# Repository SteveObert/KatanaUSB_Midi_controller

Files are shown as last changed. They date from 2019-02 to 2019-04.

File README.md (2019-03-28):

# A Teensy based USB MIDI foot controller/translator
# for Boss Katana.

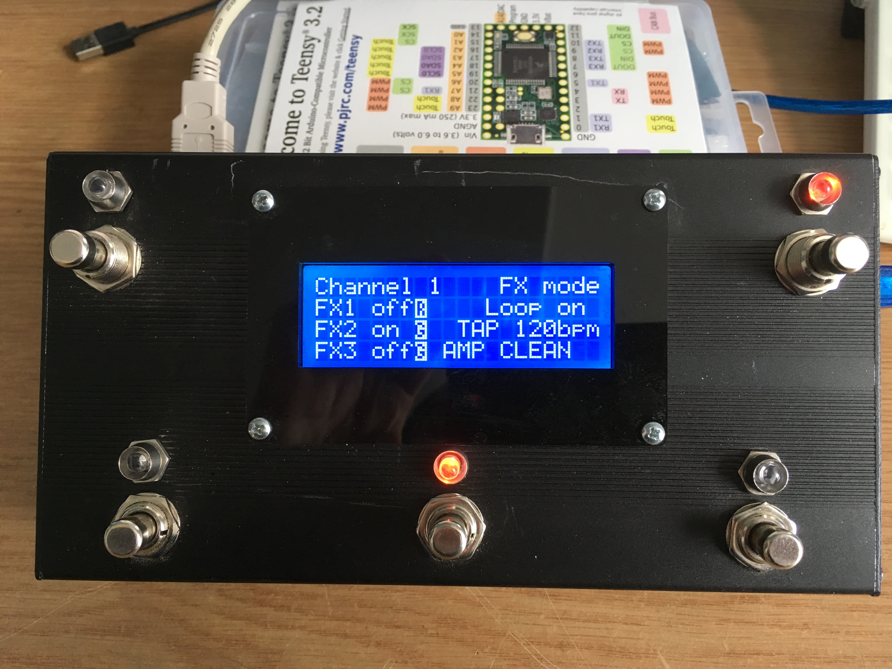
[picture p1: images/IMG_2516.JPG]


This is working prototype of a MIDI foot controller for a BOSS Katana using a Teensy 3.2. The foot controller sends sysex messages to the USB port on the Katana. The code emulates a GA-FC without additional footswitch connections (although there doesn’t seem to be any reason that’s not possible). I'm working on an expression pedal input. An expression pedal attached to an external MIDI controller can be used but requires you to adjust/write some code.

This controller can also listen to a 5 pin MIDI IN port and can be programed to translate MIDI messages (PC, CC, etc.) to sysex and forward those to a Katana. However, you must know the Katana sysex. Sending MIDI OUT from the footswitch is also possible.

It seems stable; however, it has only been tested by two people that I am aware of.

**Consider this unsupported beta software. ** If you get stuck, I may not be able to help you.

There are two versions:

In the Katana_USB_MIDI version, LCD and LEDs are updated from the Katana's USB MIDI messages. Meaning, they should take of themselves. Gumtown from the Vguitar forum deserves recognition for rewriting most of the code and adding a great deal of functionality. There is a forum thread reguarding updates and functions: https://www.vguitarforums.com/smf/index.php?topic=25185.0 

Included in the : Katana_USB_MIDI version

* Tap tempo: global or patch.

* Selectable mode for 3 foot switches, toggle either one or both FX/MOD, Delay 1/FX, and Reverb/Delay 2.

* Midi IN - control Katana patch and FX from an external MIDI controller.  *Some* CC and PC messages from the MIDI in port can be received and translated to sysex and forwarded to the Katana. If you’re looking for a more complete external MIDI to Katana you could buy the MIDX-20.

* LCD displays FX status, amp name, tempo, loop status, bank/fx mode, and channel number.

* Select Green, Yellow, or Red effect functions from the three lower foot switches.

* An expression pedal can be connected to an external MIDI controller to control 1 effect only. This is experimental and requires some coding on your part.

* Expression pedal jack input directly connected to controller and external MIDI clock IN is being worked on but not yet complete, *no ETA*.

* There is also a BOM (parts list) in this thread. This version has been tested on a Teensy 3.2 and a Teensy LC.

In the Simple sketch version, you will need to code the LCD and LEDs to work for your needs. This version is really just for testing your hardware or if you just want a starting point for your own code. The LCD and LEDs are programed to be off when you switch channels, meaning the controller expects all effects to be off. So, you'll need to change the programming if you use it differently. On this version there is no tap-tempo and no expression pedal input.

** Note I had to compile the sketches with the "fast + LTO" setting or debug, otherwise the USB mini host shield would not work. You must select the Teensy option "MIDI" when powered externally (not connected to a computer). Also, you should use the modified versions of the MS3 library included above (top of page).

Along with the Teensy 3.2, I use a Mini USB Host shield like this one: https://www.circuitsathome.com/usb-host-shield-hardware-manual/ along with the host shield library: https://github.com/felis/USB_Host_Shield_2.0.

Roland/Boss guitar gear uses a non-class compliant USB device for midi control. Additionally, there is a checksum included in each sysex message. I found this library made for the BOSS MS3:  https://github.com/MrHaroldA/MS3. Note, this library is included in the files above (top of page) and has been modified to work with the Katana instead of the MS3.
   
Here is some excellent information about sysex messages and Katana amps: https://github.com/snhirsch/katana-midi-bridge/blob/master/doc/katana_sysex.txt

The working prototype uses the library https://github.com/felis/USB_Host_Shield_2.0 and a USB host shield
(https://www.amazon.com/gp/product/B0777DR3T6/ref=ppx_yo_dt_b_asin_title_o03__o00_s00?ie=UTF8&psc=1)

I used a MIDI break out board but there no reason not to build your own MIDI in/out circuit. https://www.amazon.com/ubld-it-MIDI-Breakout-Board/dp/B00YDLVLVO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. If you don't need 5 pin MIDI IN/OUT, you can just skip this part.

What got me started on this project is a forum thread created by the author of the MS3 library: 
https://www.vguitarforums.com/smf/index.php?topic=21864.0

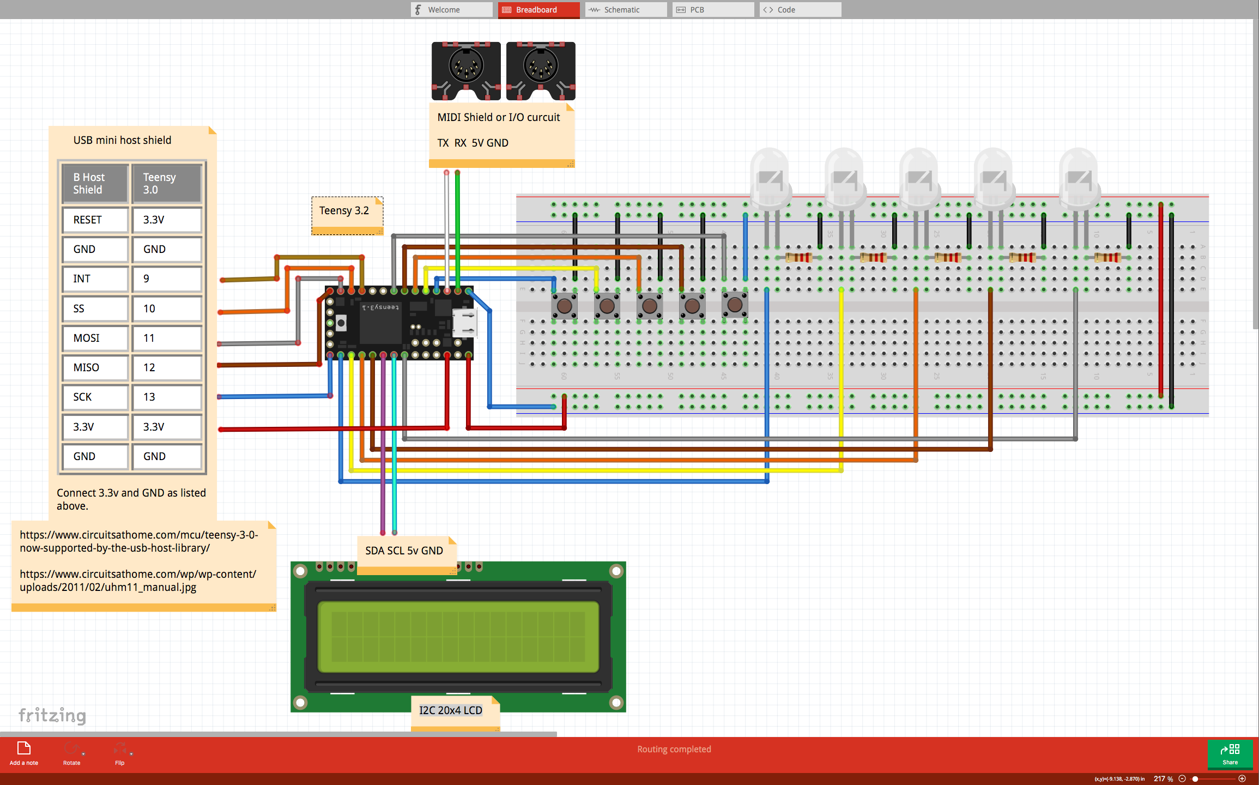
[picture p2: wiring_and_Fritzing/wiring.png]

Wiring shown above does not include expression pedals or MIDI through, see images directory for that diagram.

* I don't know if this is necessary but, I originally tested this project with an Arduino Nano and I "cut the trace inside VBUS jumper" on the host shield as mentioned in the second paragraph under the Power Options part of this page: https://www.circuitsathome.com/usb-host-shield-hardware-manual/ shown here: https://www.pjrc.com/teensy/td_libs_USBHostShield.html. I googled these pictures that show the modification for 5v microcntrollers: https://geekhack.org/index.php?PHPSESSID=jnim6u2dcno62u8vpbm8sl9ias67hb3o&action=dlattach;topic=80421.0;attach=130856;image
and https://geekhack.org/index.php?PHPSESSID=jnim6u2dcno62u8vpbm8sl9ias67hb3o&action=dlattach;topic=80421.0;attach=130858;image

These sketches have only been tested with a Teensy 3.2 and a Teensy LC. 

Inside view with messy wiring and extra holes from a previous project:

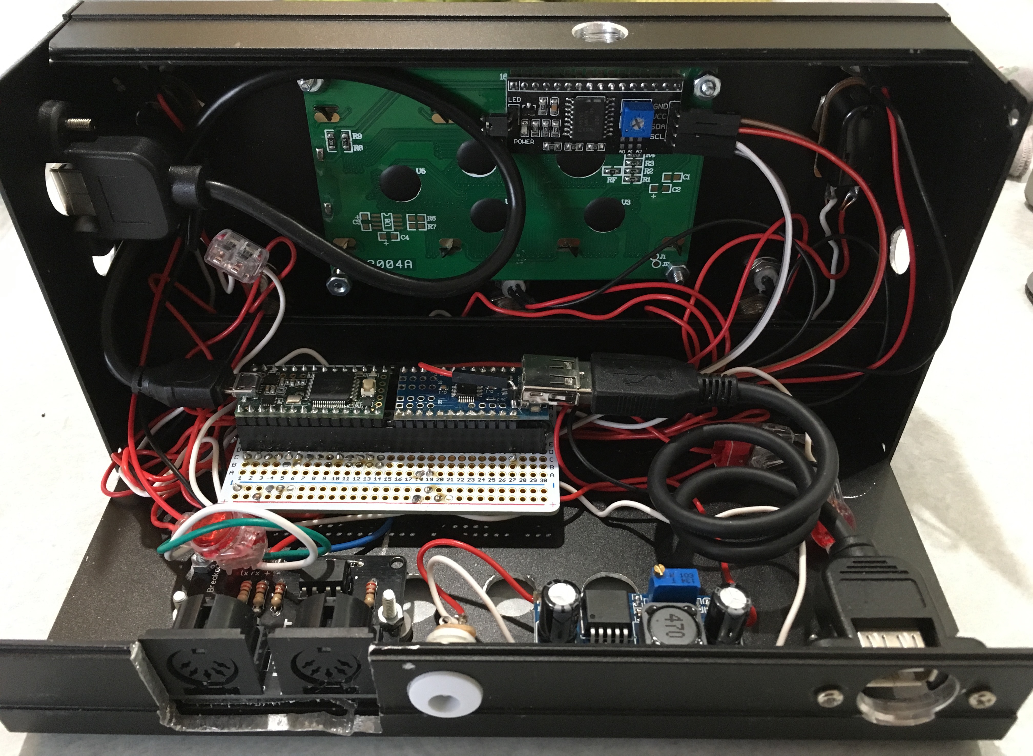
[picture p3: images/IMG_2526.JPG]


Another inside view but with a Teensy 3.6, MIDI through (untested), an extra power jack for daisy chaining, and two TRS jacks (only one is connected in the picture). A Teensy 3.2 would work just as well with ths options.

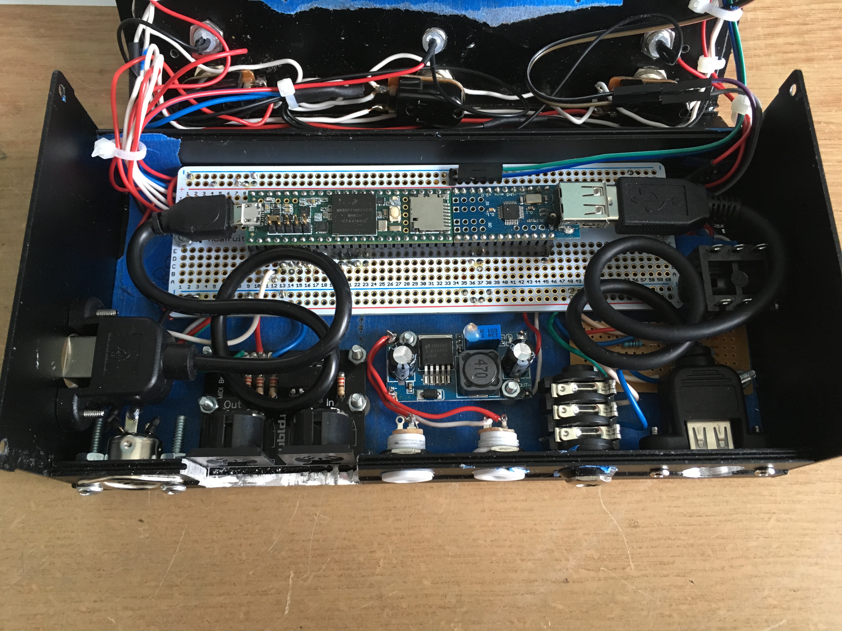
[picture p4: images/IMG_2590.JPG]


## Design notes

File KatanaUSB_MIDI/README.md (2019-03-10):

# Teensy MIDI controller for Katana 100
## Warning Beta code 

All three files must be in the same directory to complie properly.

In this version of the sketch the LCD and LEDs are updated from Katana's USB MIDI and some CC and PC messages can be sent from an external MIDI device to the Teensy via the serial MIDI IN port.

Gumtown from the Vguitar forum rewrote tons of the code in this sketch.

Included:

Tap tempo: global or patch ot (experimental MIDI Clock IN).

Selectable mode for footswitches along the bottom either one or both FX/MOD Delay 1/FX, and Reverb/Delay 2.

Selectable Katana color function for red ,green, or yellow for footswitches along the bottom either.

Midi IN - control Katana patch and FX from an external MIDI controller.

LCD displays FX status, amp name, tempo, loop status, bank/fx mode, and channel number.

An expression pedal can be connected to an external MIDI controller to control 1 effect only. this is experimental and requires some coding on your part.

Expression pedal jack input directly connected to controller and external MIDI clock IN is being worked on but not yet complete, no ETA.

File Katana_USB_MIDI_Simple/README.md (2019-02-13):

# A simple MIDI controller for Katana 100 using a Teensy controller.

## You will need to modify the LED and LCD code to match your needs.

As written the code expects that all FX are off and Loop is on when you change programms (amp channels).
Limitied MIDI IN support.

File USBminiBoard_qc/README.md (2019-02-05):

This is a slightly modified version of the USB mini host QC test found here: https://github.com/felis/USB_Host_Shield_2.0/tree/master/examples/board_qc

The modifcation just does not halt the sketch should the "die revision" test fail.

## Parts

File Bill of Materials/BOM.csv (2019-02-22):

Teensy 3.2 or LC | https://www.pjrc.com/store/teensy32.html
USB mini host shield | https://www.amazon.com/dp/B01EWW9R1E/?coliid=ILRDGVK1ADBLT&colid=34R848U9NQQ2P
20x4 LCD with I2C backpack: (note you only need one): | https://www.amazon.com/JANSANE-Arduino-Display-Interface-Raspberry/dp/B07D7ZQVDR?s=electronics
5 LEDs
5 resistors for LEDs
5 LED bezels
5 normally open momentary footswitches. | https://lovemyswitches.com/spst-momentary-foot-switch-normally-open-soft-touch/
Power jack for use with pedal board power supply (optional) | https://lovemyswitches.com/lumberg-switched-dc-power-jack-2-1mm/
Strip (vero or tag) board used to solder wiring | https://www.adafruit.com/product/1609
Female header pins for the strip board and Teensy/mini usb shield.
Some type of footswitch enclosure. I used one of these: | https://www.ebay.com/itm/Aluminum-DIY-Project-Box-Enclosure-Case-PCB-Amplifier-Electronic-200-105-55mm/142615103868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
USB micro to USB Female B panel mount cable: (optional) | https://www.ebay.com/itm/USB-Cable-Panel-Mount-Type-B-Female-to-Micro-B-Male-Enclosure-Case-Raspberry-Pi/181687616398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
Panel mount USB cable. Example | https://www.adafruit.com/product/908
9v to 5v step down power converter (optional for using with 9v) | https://www.ebay.com/itm/LM2596S-DC-DC-3A-Buck-Adjustable-Step-down-Power-Supply-Converter-Module-Arduino/382552225398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
MIDI “breakout board” or make your own MIDI IN/OUT circuit. | https://www.amazon.com/ubld-it-MIDI-Breakout-Board/dp/B00YDLVLVO
A bezel for the LCD. Make your own | https://www.tindie.com/products/WIDGENEERING/20x4-lcd-bezel-with-clear-backplate/
Stand offs, bolts , and nuts to mount LCD and other stuff to enclosure.

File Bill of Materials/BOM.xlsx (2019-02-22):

Teensy 3.2 (Other model Teensys may work…)
USB mini host shield. I used this one: | https://www.amazon.com/dp/B01EWW9R1E/?coliid=ILRDGVK1ADBLT&colid=34R848U9NQQ2P
20x4 LCD with I2C backpack: I used one of these (note you only need one): | https://www.amazon.com/JANSANE-Arduino-Display-Interface-Raspberry/dp/B07D7ZQVDR?s=electronics
5 LEDs
5 resistors for LEDs
5 LED bezels
5 normally open momentary footswitches. Such as: | https://lovemyswitches.com/spst-momentary-foot-switch-normally-open-soft-touch/
Power jack for use with pedal board power supply if you don’t want to power with Teensy’s USB port. Example: | https://lovemyswitches.com/lumberg-switched-dc-power-jack-2-1mm/
Strip (vero or tag or solderable breadboard) board used to solder wiring. Example: | https://www.adafruit.com/product/1609
Female header pins for the strip board and Teensy/mini usb shield.
Some type of footswitch enclosure. I used one of these: | https://www.ebay.com/itm/Aluminum-DIY-Project-Box-Enclosure-Case-PCB-Amplifier-Electronic-200-105-55mm/142615103868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
USB micro to USB Female B panel mount cable: | https://www.ebay.com/itm/USB-Cable-Panel-Mount-Type-B-Female-to-Micro-B-Male-Enclosure-Case-Raspberry-Pi/181687616398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
Panel mount USB cable. Example: | https://www.adafruit.com/product/908
9v to 5v step down power convertor such as: | https://www.ebay.com/itm/LM2596S-DC-DC-3A-Buck-Adjustable-Step-down-Power-Supply-Converter-Module-Arduino/382552225398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
MIDI “breakout board” or make your own MIDI IN/OUT circuit. Breakout board example: | https://www.amazon.com/ubld-it-MIDI-Breakout-Board/dp/B00YDLVLVO
A bezel for the LCD. Something like this: | https://www.tindie.com/products/WIDGENEERING/20x4-lcd-bezel-with-clear-backplate/
stand offs, bolts , and nuts to mount LCD and other stuff to enclosure.

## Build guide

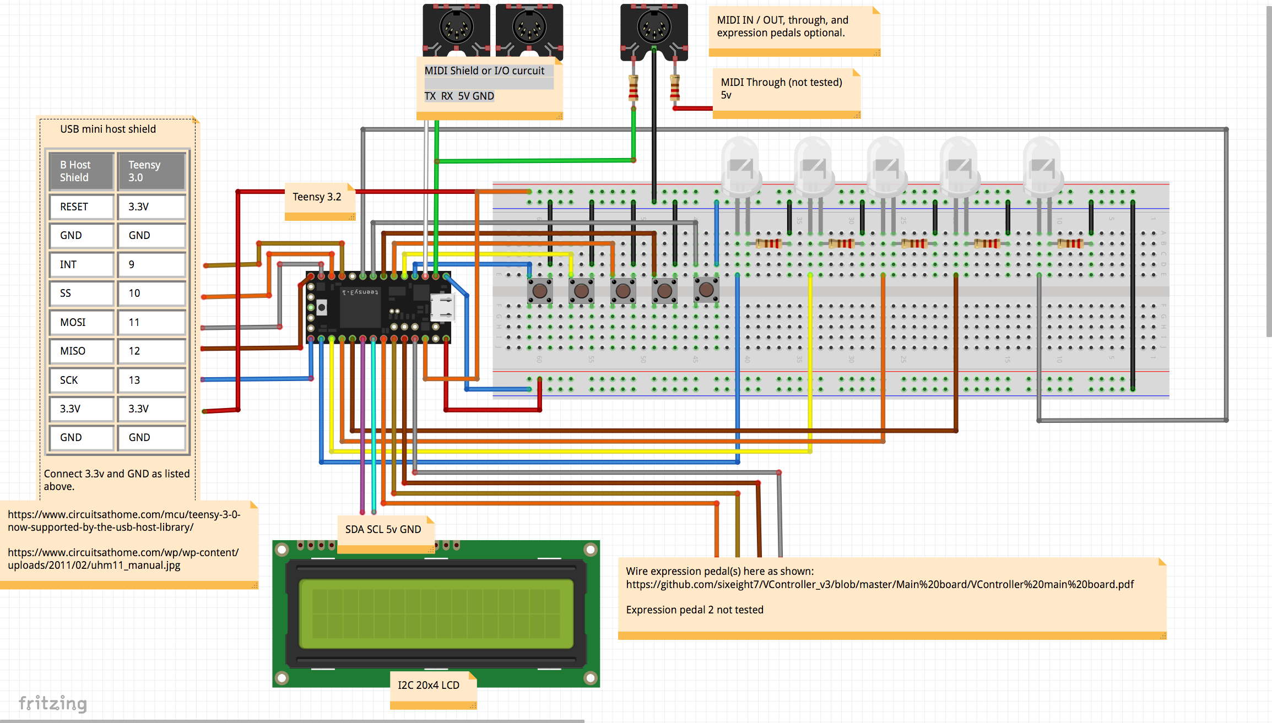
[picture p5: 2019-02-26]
Fritzing/wiring_exp_MIDI_Through.png

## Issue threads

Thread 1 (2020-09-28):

ARDUINO 1.8.13 refuses to compile.

mizreh, 2020-09-28:
Hello,
my name is Alain, I am based in France, and I would like to try your version for the Katana Amp, which I own since a few weeks.
However, with the Arduino compiler I get the error that the USB Host is meant for SAM version (32 bits), which I thought TEENSY was... but it uses AVR Architecture...
Quite strange to me.

Have I done something wrong ?

Thanks for the help,

Alain

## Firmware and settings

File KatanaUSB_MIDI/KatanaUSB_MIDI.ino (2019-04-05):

// Put all three files in the same directory before compiling!
// List of To Do items
// 1. Allow expression pedal 1 automatically change to controll assigned parameter with patch change.
// 2. Support expression pedal 2.
// 3. Allow expression pedal(s) to automatically switch assigned effect off/on (partialy done for pedal 1).
// 4. Update LCD screen to show more useful information. Perhaps, show selected effect name instead of FX1 on/off.
// 5. Loop on/off LCD text could be replaced with something else as there is a status LED anyway.

// Uncomment this to enable verbose debug messages.
//#define MS3_DEBUG_MODE
//uncomment below to debug withot the Katana connected.
//#define MS3_OVERRIDE_MODE

#include "MS3.h"
//#include <Wire.h>       //use this for Teensy LC
#include <i2c_t3.h>   // use this for Teensy 3.1/3.2
#include <LCD.h>
#include <LiquidCrystal_I2C.h>
#include <EEPROM.h>
#include <JC_Button.h>
#include <MIDI.h>

#define TOTAL_LED 5

// Initialize the MS3 class.
MS3 MS3;

// These are addresses for the effect states.
static const uint32_t P_BSTR_SW =    0x60000030;
static const uint32_t P_BSTR_TYPE =  0x60000031;
static const uint32_t P_AMP =        0x60000051;
static const uint32_t P_MOD_SW =     0x60000140;
static const uint32_t P_FX_SW =      0x6000034C;
static const uint32_t P_DD1_SW =     0x60000560;
static const uint32_t P_DD1_TIME =   0x60000562;
static const uint32_t P_REV_SW =     0x60000610;
static const uint32_t P_SR_SW =      0x60000655;
static const uint32_t P_DD2_SW =     0x6000104E;
static const uint32_t P_DD2_TYPE =   0x6000104F;
static const uint32_t P_DD2_TIME =   0x60001050;
static const uint32_t P_BSTR_RGY =   0x60001210; //0x00000410;
static const uint32_t P_MOD_RGY =    0x60001211;
static const uint32_t P_DD1_RGY =    0x60001212;
static const uint32_t P_FX_RGY =     0x60001213; //0x00000411;
static const uint32_t P_REVDD2_RGY = 0x60001214; //0x00000412;
static const uint32_t P_RGY_EFFECTS = 0x60001201; //15 bytes request


// sysex control define ################################
static const uint32_t PC =        0x00010000; // change channel MS3.write(PC, 1, 2) second byte is channel number 3rd is length
static const uint32_t fx1_sw =    0x60000030; //turn button 1 on  MS3.write(fx1_sw, 1, 1) second byte 0 = off 1 = on
static const uint32_t fx2_sw =    0x6000034C; //turn button 2 on  MS3.write(fx2_sw, 1, 1) second byte 0 = off 1 = on
static const uint32_t fx3_sw =    0x60000610; //turn reverb on  MS3.write(fx3_sw, 1, 1) second byte 0 = off 1 = on
static const uint32_t Loop_sw =   0x60000655;   // turn loop off on
static const uint32_t rvbYellow = 0x60001214; // set reverb type to yellow
static const uint32_t express =   0x6000015D; // expression pedal position ??
static const uint32_t FV_PDL =    0x60000710; // GA-FC volume pedal address MS3.write(FV_PDL, 0-63, 1)
static const uint32_t FV2_PDL =   0x60000633; // GA-FC FX pedal address also for foot pedal connected to amp
static const uint32_t testPdl =   0x00000630; // foot vol??
static const uint32_t wah_pedal = 0x60000369; // expression pedal Wah position
//static const uint32_t rotary_expPedal = 0x6000051A //  rotary expression pedal position
//0x00000428 // acts like GA-FC delay/fx button
// end sysex define ##############################

// define custom lcd character set (gliphs) for inverted R G Y.
static uint8_t custom_O[8] = { 0b11111, 0b11111, 0b11111, 0b11111, 0b00000, 0b11111, 0b11111, 0b11111 };
static uint8_t custom_Y[8] = { 0b11111, 0b10011, 0b10101, 0b10101, 0b10011, 0b10101, 0b10101, 0b11111 };
static uint8_t custom_R[8] = { 0b11111, 0b10101, 0b10101, 0b10101, 0b11011, 0b11011, 0b11011, 0b11111 };
static uint8_t custom_G[8] = { 0b11111, 0b10011, 0b01101, 0b01111, 0b01001, 0b01101, 0b10011, 0b11111 };

// This is the address for the program change.
const uint32_t P_PATCH = 0x00010000;

// We're going to check and report these effect blocks.
const uint32_t CHECK_THIS[] = {
  P_BSTR_SW,
  P_MOD_SW,
  P_FX_SW,
  P_DD1_SW,
  P_SR_SW,
  P_REV_SW,
  P_DD2_SW,
  P_AMP,
  P_BSTR_RGY,
  P_MOD_RGY,
  P_DD1_RGY,
  P_FX_RGY,
  P_REVDD2_RGY,
  P_DD1_TIME,
  P_RGY_EFFECTS
};
const uint8_t CHECK_THIS_SIZE = sizeof(CHECK_THIS) / sizeof(CHECK_THIS[0]);

static const char *amp_list[] {"Nat Cln", "ACOUSTC", "CmCrnch", "StCrnch", "HiGnStk", "Pwr Drv", "ExtLead", "CoreMtl", "CLEAN  ", "ClnTwin",
  "PrCrnch", "CRUNCH ", "DxCrnch", "VoDrive", "VO Lead", "MtchDrv", "BG Lead", "BgDrive", "MS-59 I", "MS59 II",
  "RFr Vnt", "RFrMdrn", "TAmp Ld", "BROWN  ", "LEAD   ", "Custom "
};
static const char *bstr_list[] {"Mid Bst", "Cln Bst", "TrblBst", "Crunch", "Ntrl OD", "Warm OD", "Fat DS", "Lead DS", "Mtl DS", "OCT Fuz",
  "BluesOD", "OD-1", "TubScrm", "TurboOD", "Dist", "Rat", "GuV DS", "DST+", "MtlZone", "60sFuzz", "Muf Fuz", "Custom"
};
static const char *fx_list[] {"T.Wah", "AutoWah", "PdlWah", "AdvComp", "Limitr", "OD/DS", "GrphcEQ", "ParaEQ", "T Modfy", "Gtr Sim", "SlwGear",
  "DeFretr", "WavSyn", "SitrSim", "Octave", "P Shift", "Harmony", "SndHold", "AC.Proc", "Phaser", "Flanger", "Tremolo",
  "Rotary1", "Uni-V", "Panner", "Slicer", "Vibrato", "RingMod", "Humnizr", "2X2 CHR", "SubDly", "AcGtSim", "Rotary2",
  "TeraEco", "OvrTone", "Phser90", "Flgr117", "Wah95E", "DlyCh30"
};
static const char *delay_list[] {"Single", "Pan", "Stereo", "Series", "Paralel", "L/R", "Reverse", "Analog", "Tape", "Mod", "SDE3000"};
static const char *reverb_list[] {"Ambienc", "Room", "Hall 1", "Hall 2", "Plate", "Spring", "Modulte"};

// Some global variables to store effect state and if something changed.
uint32_t states = 0;  // stores true/false bit of the first 8 effects parsed.
uint32_t checked = 0;
bool changed = false;
uint32_t timerStart = 0;
uint32_t tapTimerStart = 0;
uint32_t tempoMillis = 0;
uint32_t tapTimerMode = 0;
uint32_t byte_array[15]; //store parameter byte from each (15) effects when parsed.
uint32_t tapTime = 0;
uint32_t totalTime = 0;

Button footSw5(2, 50);       // define the button to pin 2, 50ms debounce. Function switch
Button footSw1(3, 50);       // define the button to pin 3, 50ms debounce. FX1 switch
Button footSw2(4, 50);       // define the button to pin 4, 50ms debounce. FX2 switch
Button footSw3(5, 50);       // define the button to pin 5, 50ms debounce. FX3 switch
Button footSw4(6, 50);       // define the button to pin 6, 50ms debounce. Tap/Loop switch
bool long_press_release = 0;  // so we know a long press occured, and mask out a switch release operation directly after.
uint16_t LONG_PRESS((EEPROM.read(0) + 2) * 100); // we define a "long press" hold time to be stored value+2 x 100 milliseconds.
uint8_t fx1_sel = EEPROM.read(1);  // read the stored setting for FX1 whether Both, Booster only, MOD only.
uint8_t fx2_sel = EEPROM.read(2);  // read the stored setting for FX2 whether Both, Delay1 only, FX only.
uint8_t fx3_sel = EEPROM.read(3);  // read the stored setting for FX3 whether Both, Reverb only, Delay2 only.
uint8_t tapT_sel = EEPROM.read(4); // read the stored setting for TAP delay whether from Patch, Global, or external carried to next patch.
uint8_t tapDD2_sel = EEPROM.read(5); // read the stored setting for Delay2 TAP whether Patch (unaffected), or tempo signature of Delay1 TAP.


//uint32_t count = 0;
const uint8_t led1 = A0;
const uint8_t led2 = A1;
const uint8_t led3 = A2;
const uint8_t led4 = A3;
const uint8_t led5 = A6;
const uint8_t ledArray[] = {led1, led2, led3, led4, led5};
bool fx1State = 1;
bool fx2State = 1;
bool fx3State = 1;
bool modState = 1;
bool fxState = 1;
bool dd2State = 1;
bool loopState = 1;
uint8_t bstr_rgy_state = 0;
uint8_t mod_rgy_state = 0;
uint8_t dd1_rgy_state = 1;
uint8_t fx_rgy_state = 1;
uint8_t revdd2_rgy_state = 2;
/*uint8_t bstr_G_type = 1;
  uint8_t bstr_R_type = 2;
  uint8_t bstr_Y_type = 3;
  uint8_t mod_G_type = 1;
  uint8_t mod_R_type = 5;
  uint8_t mod_Y_type = 8;
  uint8_t fx_G_type = 2;
  uint8_t fx_R_type = 6;
  uint8_t fx_Y_type = 9;
  uint8_t dd1_G_type = 1;
  uint8_t dd1_R_type = 2;
  uint8_t dd1_Y_type = 3;
  uint8_t rev_G_type = 1;
  uint8_t rev_R_type = 2;
  uint8_t rev_Y_type = 3;*/
uint8_t dd2_G_type = 1;
uint8_t dd2_R_type = 2;
uint8_t dd2_Y_type = 3;
uint8_t currentChannel = 1; // active amp channel
String message_1 = "FX1 on ";  // predefined lcd text for test mode, current state is read in from the Katana.
String message_2 = "FX2 on ";
String message_3 = "FX3 on ";
String message_4 = "Loop on";
String message_5 = "";
String message_6 = "AMP Brown";
uint32_t type, MIDIchannel, data1, data2, number, value;
//uint8_t midiByte = 0 ;
const uint32_t msg = 0;
uint8_t chnMode = 0;    // Bank 1, bank 2, or fx button mode
uint32_t previousMillis = 0;         // will store last time LED was updated - used for blinking when select bank 2 is active
const long interval = 300;                // blink time for  select bank 2 is active
uint8_t ledState = LOW;                       // blink time for  select bank 2 is active
uint8_t  set_rgy_select = 0;
uint8_t  rgy_num = 0;
uint16_t tempo = 120;
uint8_t menu = 0;

// variables for expression pedal(s)
uint16_t pedalVal1 = 0;           // Expression pedal 1 reading
uint16_t lastPedalVal1 = 0;       // used to see if there is a change in pedal position since last reading
uint8_t pedalOn1 = 0;             // was the exp pedal used?
uint32_t pedalDelay = 1000;       // If epression pedal is toe down and hasn't moved for this time switch effect off
uint8_t pedalOnThreshold = 62;    // An expression pedal value greater than this value for more than the value above will automatically switch FX2 off.
uint32_t lastRead1 = 0;           // last reading of expression pedal 1
uint8_t expressionPedal1Pin = 8;  // TRS tip for expression pedal 1
uint8_t expressionPedal1RingPin = 7;// TRS ring for expression pedal 1
uint8_t exp1Connected_sel = EEPROM.read(6); // read the stored setting to see if expression pedal 1 is connected. 1 = yes, 2 = no
uint8_t exp2Connected_sel = EEPROM.read(7); // read the stored setting to see if expression pedal 1 is connected. 1 = yes, 2 = no
uint8_t exp1Calibrated_sel = EEPROM.read(8); // read the stored setting to see if expression pedal 1 is connected. 1 = yes, 2 = no
uint16_t exp1Min = EEPROM.read(9); // The minimum value read from expression pedal 1 the last time it was calibrated
uint16_t exp1Max = 0;
// exp1Max is the maximum value read from expression pedal 1 the last time it was calibrated -- EEprom.put is run in setup funct
//EEPROM.get( 10, exp1Max );



// variables for external MIDI IN clock
// these variables are used when an external MIDI clock
// is sent to the 5 pin DIN MIDI IN. Can be set in tempo
// options in the settings menu.
uint32_t MidiClockTime = 0;
uint32_t LastClkRead = 0;
float extTempo = 0;
uint8_t countClk = 0;
uint32_t deltaT[25];
float AvgClkTime = 0;
uint32_t TotalTime = 0;
uint32_t avgTime = 0;
uint32_t oldTemp = 0;


// Initialize LCD
// Choose or set your display's I2C address. Two common values are below.
// use one of the two unless yours is different.
#define I2C_ADDR1    0x3F // LCD1 Address [A0=open   A1=open   A2=open  ]
//#define I2C_ADDR1    0x27 // LCD1 Address [A0=open   A1=open   A2=open  ]
#define BACKLIGHT_PIN 3
#define EN_PIN  2
#define RW_PIN  1
#define RS_PIN  0
#define D4_PIN  4
#define D5_PIN  5
#define D6_PIN  6
#define D7_PIN  7

LiquidCrystal_I2C  lcd1(I2C_ADDR1, EN_PIN, RW_PIN, RS_PIN, D4_PIN, D5_PIN, D6_PIN, D7_PIN);
// Note: some lcd I2C chipsets with all address links open are 0x27 and some are 0x3F.

// This creatce a MIDI instance for the 5 pin MIDI IN/OUT connection.
MIDI_CREATE_INSTANCE(HardwareSerial, Serial1, MIDI);

// Loop to turn all LEDs off
void setAllLEDs(uint8_t state) {
  for (uint8_t i = 0; i < TOTAL_LED; i++) {
    digitalWrite(ledArray[i], state);
  }
}

// blink the leds at start up
void blinkAllLeds(uint8_t numTimes, uint16_t inDelay) {
  lcd1.setCursor(0, 1);
  for (uint8_t j = 0; j < numTimes; j++) {
    for (uint8_t i = 0; i < TOTAL_LED; i++) {
      digitalWrite(ledArray[i], HIGH);
      delay(inDelay);
      digitalWrite(ledArray[i], LOW);
      lcd1.print(".");
    }
  }
}

// If USB connection is lost set the katana back in BTS edit mode
void setEdit(void) {
  uint32_t test = 0;
  uint8_t dataTest = 0;
  Serial.println();
  Serial.println(F("Waiting..."));
  Serial.println();
  MS3.begin();
  //katana.update(test, dataTest);
  delay(100);
  switch (MS3.update(test, dataTest)) {
    case MS3_READY:
      Serial.println(F("############ Now I'm ready!"));
      Serial.println();
      MS3.setEditorMode();
      MS3.read(PC, 0x02);
      break;
  }
}

// ###########################################
// Begin setup
// ###########################################
/**
   Setup routine.*****************************************************
*/
void setup() {
  Wire.begin();
  Serial.begin(115200);
  //Serial.begin(31250);
  lcd1.begin (20, 4); //  LCD1 is 20x4 - for some reason Teensy 3.6 needs this line twice
  // delay(1000);
  MIDI.begin(MIDI_CHANNEL_OMNI);          // Listen on all MIDI channels
  MIDI.setHandleProgramChange(MIDIinPC);  // Run MIDIinPC() function if Program change received.
  MIDI.setHandleControlChange(MIDIinCC);  // Run MIDIinCC() function if Control change received.
  MIDI.setHandleClock(MIDIinClock);       // Run MIDIinClock() function if external MIDI Clock in present and enabled

  footSw1.begin();
  footSw2.begin();
  footSw3.begin();
  footSw4.begin();
  footSw5.begin();

  pinMode(led1, OUTPUT);
  pinMode(led2, OUTPUT);
  pinMode(led3, OUTPUT);
  pinMode(led4, OUTPUT);
  pinMode(led5, OUTPUT);
  //Wire.setClock(1000000L);  // May not be necessary
  // set LEDS and initial display text
  lcd1.begin (20, 4); //  LCD1 is 20x4

  lcd1.setBacklightPin(BACKLIGHT_PIN, POSITIVE);
  lcd1.setBacklight(HIGH);
  lcd1.createChar(0, custom_O);  // load custom characters in LCD CGRAM
  lcd1.createChar(1, custom_G);
  lcd1.createChar(2, custom_Y);
  lcd1.createChar(3, custom_R);
  lcd1.setCursor(0, 0);
  lcd1.print("Initializing...");  // Not required
  blinkAllLeds(1, 200);
  setAllLEDs(LOW);
  lcd1.clear();

  //while (!Serial) {}  // comment out if not deBugging

  if (!MS3.begin()) {
    Serial.println(F("*** USB / MS3 init error! ***"));
    while (true);
  }

  Serial.println();
#ifdef MS3_OVERRIDE_MODE
  updateLCD1();
#endif

  // Set editor mode - This is necessary because the Katana unsets
  // editor mode if powered off
  uint32_t parameter = 0;
  uint8_t data = 0;
  uint8_t editMode = 0;
  while (editMode == 0) {
    switch (MS3.update(parameter, data)) {
      case MS3_NOT_READY:
        Serial.println(F("Katana OFFLINE !"));
        Serial.println();
        message_1 = "*      KATANA      *";
        message_2 = "*      OFFLINE     *";
        updateLCD1 ();
        delay(100);
        break;
      case MS3_READY:
        MS3.setEditorMode();
        MS3.read(P_PATCH, 0x02);
        lcd1.clear();
        updateLCD1 ();
        editMode = 1;
        Serial.println(F("Ready!"));
        break;
    }
  }
  EEPROM.get( 10, exp1Max ); // The maximum value read from expression pedal 1 the last time it was calibrated
}
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

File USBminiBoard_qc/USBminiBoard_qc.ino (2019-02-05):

/* USB Host Shield 2.0 board quality control routine */
/* To see the output set your terminal speed to 115200 */
/* for GPIO test to pass you need to connect GPIN0 to GPOUT7, GPIN1 to GPOUT6, etc. */
/* otherwise press any key after getting GPIO error to complete the test */
/**/
#include <usbhub.h>

// Satisfy the IDE, which needs to see the include statment in the ino too.
#ifdef dobogusinclude
#include <spi4teensy3.h>
#include <../../../../hardware/pic32/libraries/SPI/SPI.h> // Hack to use the SPI library
#endif
#include <SPI.h> // Hack to use the SPI library

/* variables */
uint8_t rcode;
uint8_t usbstate;
uint8_t laststate;
//uint8_t buf[sizeof(USB_DEVICE_DESCRIPTOR)];
USB_DEVICE_DESCRIPTOR buf;

/* objects */
USB Usb;
//USBHub hub(&Usb);

void setup() {
        laststate = 0;
        Serial.begin(115200);
#if !defined(__MIPSEL__)
        while(!Serial); // Wait for serial port to connect - used on Leonardo, Teensy and other boards with built-in USB CDC serial connection
#endif
        E_Notify(PSTR("\r\nCircuits At Home 2011"), 0x80);
        E_Notify(PSTR("\r\nUSB Host Shield Quality Control Routine"), 0x80);
        /* SPI quick test - check revision register */
        E_Notify(PSTR("\r\nReading REVISION register... Die revision "), 0x80);
        Usb.Init(); // Initializes SPI, we don't care about the return value here
        {
                uint8_t tmpbyte = Usb.regRd(rREVISION);
                switch(tmpbyte) {
                        case( 0x01): //rev.01
                                E_Notify(PSTR("01"), 0x80);
                                break;
                        case( 0x12): //rev.02
                                E_Notify(PSTR("02"), 0x80);
                                break;
                        case( 0x13): //rev.03
                                E_Notify(PSTR("03"), 0x80);
                                break;
                        default:
                                E_Notify(PSTR("invalid. Value returned: "), 0x80);
                                print_hex(tmpbyte, 8);
                                //halt55();
                                break;
                }//switch( tmpbyte...
        }//check revision register
        /* SPI long test */
        {
                E_Notify(PSTR("\r\nSPI long test. Transfers 1MB of data. Each dot is 64K"), 0x80);
                uint8_t sample_wr = 0;
                uint8_t sample_rd = 0;
                uint8_t gpinpol_copy = Usb.regRd(rGPINPOL);
                for(uint8_t i = 0; i < 16; i++) {
#ifdef ESP8266
                        yield(); // needed in order to reset the watchdog timer on the ESP8266
#endif
                        for(uint16_t j = 0; j < 65535; j++) {
                                Usb.regWr(rGPINPOL, sample_wr);
                                sample_rd = Usb.regRd(rGPINPOL);
                                if(sample_rd != sample_wr) {
                                        E_Notify(PSTR("\r\nTest failed.  "), 0x80);
                                        E_Notify(PSTR("Value written: "), 0x80);
                                        print_hex(sample_wr, 8);
                                        E_Notify(PSTR(" read: "), 0x80);
                                        print_hex(sample_rd, 8);
                                        halt55();
                                }//if( sample_rd != sample_wr..
                                sample_wr++;
                        }//for( uint16_t j...
                        E_Notify(PSTR("."), 0x80);
                }//for( uint8_t i...
                Usb.regWr(rGPINPOL, gpinpol_copy);
                E_Notify(PSTR(" SPI long test passed"), 0x80);
        }//SPI long test
        /* GPIO test */
        /* in order to simplify board layout, GPIN pins on text fixture are connected to GPOUT */
        /* in reverse order, i.e, GPIN0 is connected to GPOUT7, GPIN1 to GPOUT6, etc. */
        {
                uint8_t tmpbyte;
                E_Notify(PSTR("\r\nGPIO test. Connect GPIN0 to GPOUT7, GPIN1 to GPOUT6, and so on"), 0x80);
                for(uint8_t sample_gpio = 0; sample_gpio < 255; sample_gpio++) {
#ifdef ESP8266
                        yield(); // needed in order to reset the watchdog timer on the ESP8266
#endif
                        Usb.gpioWr(sample_gpio);
                        tmpbyte = Usb.gpioRd();
                        /* bit reversing code copied vetbatim from http://graphics.stanford.edu/~seander/bithacks.html#BitReverseObvious */
                        tmpbyte = ((tmpbyte * 0x0802LU & 0x22110LU) | (tmpbyte * 0x8020LU & 0x88440LU)) * 0x10101LU >> 16;
                        if(sample_gpio != tmpbyte) {
                                E_Notify(PSTR("\r\nTest failed. Value written: "), 0x80);
                                print_hex(sample_gpio, 8);
                                E_Notify(PSTR(" Value read: "), 0x80);
                                print_hex(tmpbyte, 8);
                                E_Notify(PSTR(" "), 0x80);
                                press_any_key();
                                break;
                        }//if( sample_gpio != tmpbyte...
                }//for( uint8_t sample_gpio...
                E_Notify(PSTR("\r\nGPIO test passed."), 0x80);
        }//GPIO test
        /* PLL test. Stops/starts MAX3421E oscillator several times */
        {
                E_Notify(PSTR("\r\nPLL test. 100 chip resets will be performed"), 0x80);
                /* check current state of the oscillator */
                if(!(Usb.regRd(rUSBIRQ) & bmOSCOKIRQ)) { //wrong state - should be on
                        E_Notify(PSTR("\r\nCurrent oscillator state unexpected."), 0x80);
                        press_any_key();
                }
                /* Restart oscillator */
                E_Notify(PSTR("\r\nResetting oscillator\r\n"), 0x80);
                for(uint16_t i = 0; i < 100; i++) {
#ifdef ESP8266
                        yield(); // needed in order to reset the watchdog timer on the ESP8266
#endif
                        E_Notify(PSTR("\rReset number "), 0x80);
                        Serial.print(i, DEC);
                        Usb.regWr(rUSBCTL, bmCHIPRES); //reset
                        if(Usb.regRd(rUSBIRQ) & bmOSCOKIRQ) { //wrong state - should be off
                                E_Notify(PSTR("\r\nCurrent oscillator state unexpected."), 0x80);
                                halt55();
                        }
                        Usb.regWr(rUSBCTL, 0x00); //release from reset
                        uint16_t j = 0;
                        for(j = 1; j < 65535; j++) { //tracking off to on time
                                if(Usb.regRd(rUSBIRQ) & bmOSCOKIRQ) {
                                        E_Notify(PSTR(" Time to stabilize - "), 0x80);
                                        Serial.print(j, DEC);
                                        E_Notify(PSTR(" cycles\r\n"), 0x80);
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

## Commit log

2019-02-05 Modified USN mini host board test
2019-02-05 Corrected LED5 pin to match wiring diagram
2019-02-08 Set LED 5 to correct pin
2019-02-13 modified to use teensy I2c lib
2019-02-13 LCD doesn't update from Katana
    LCD status FX on/off must be manually updated in code.
    [Katana_USB_MIDI_Simple.ino]
2019-02-13 LCD gets updates from Katana
    LCD is updated from Katana unlike other version (simple) where LCD and LEDS must be updated in code.
2019-02-17 #include <i2c_t3.h> instead of Wire.h
2019-02-17 #include "i2c_t3.h" // teensy i2c library
2019-02-27 Changed variable types
    fixed all compiler warnings except for one
    [KatanaUSB_MIDI.ino]
2019-03-04 wiring with expression pedal
    moved one LED pin to allow for to stereo jacks to be used with expression pedals external/switches.
2019-03-05 updated wiring caption
2019-03-10 expression pedal improvements
    Added expression pedal auto detect if pedal is wired like Vcontroller.
2019-03-27 updated enclosure
